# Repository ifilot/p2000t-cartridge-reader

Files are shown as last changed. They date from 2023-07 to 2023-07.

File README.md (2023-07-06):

# P2000T Cartridge Reader

This repository contains hard- and software utilities to read P2000T cartridges
using an [Arduino Leonardo](https://docs.arduino.cc/hardware/leonardo) board.
The repository is organized as follows. The [arduino](arduino) folder contains
the source code for the Arduino Leonardo. In the [kicad](kicad) folder the
files can be found for the arduino shield board. Finally, in the [script](scripts)
folder a number of Python scripts can be found interfacing with the Arduino
Leonardo board to dump cartridge roms to a file.

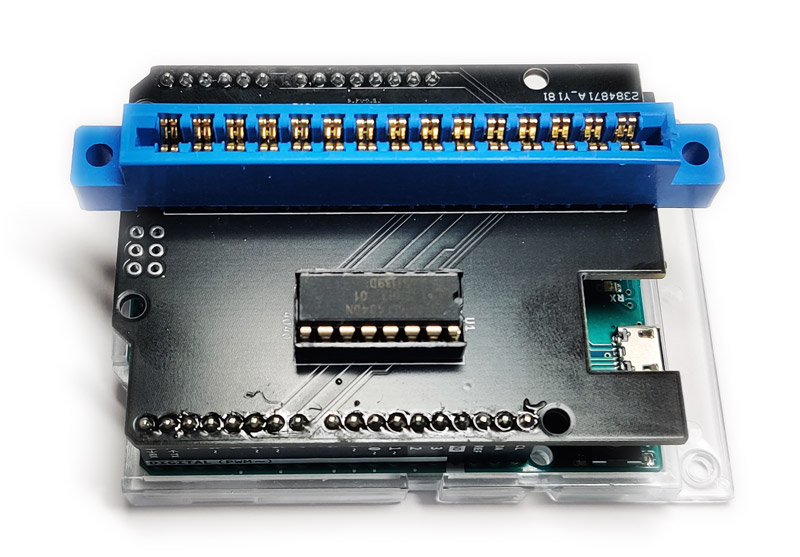
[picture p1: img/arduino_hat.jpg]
Arduino hat


## Kicad scheme

Kicad scheme

## Uploading the firmware

Open the [Arduino IDE](https://www.arduino.cc/en/software) and open the file
`cartridge_reader_firmware.ino`. Verify that the source code can be correctly
compiled and upload it to the Arduino Leonardo. Next, proceed to the Python
files as found below. Test that the interface is functioning and then use
the `readrom.py` file to dump the cartridges.

## Python files

The following three Python files are provided to interface with the Arduino
Leonardo Board. To work with these files, you need to have the
[pyserial](https://pypi.org/project/pyserial/) package installed.

* [serialtest.py](scripts/serialtest.py): Tests whether Python can succesfully
  interface with the Arduino Leonardo and the cartridge reader firmware.
* [comparison_test.py](scripts/comparison_test.py): Tests whether the standard
  basic cartridge can be succesfully read. This requires one to have such a
  cartridge in their possession.
* [readrom.py](scripts/readrom.py): Dumps the contents of the cartridge in
  a `rom.bin` file. The `rom.bin` file is stored in the same folder as where
  this file resides.

## Logic table

In the table below, the interfacing of the Arduino pins to the signals on the
P2000T cartridge can be found. This interfacing scheme has been designed
around the documentation as found [here](https://www.philips-p2000t.nl/cartridges/basic-cartridge).
**It should be explicitly mentioned that the scheme as found in the Field Support
Manual is erroneous and has the CARSEL1 (CS1) and CARSEL2 (CS2) pins swapped.**

| BANK | D8 / A12B | D2 / ~CS1 | D3 / ~CS2 | A12  | A13  | ~CS  |
|---|---|---|---|---|---|---|
|`0x00`| HIGH | LOW | HIGH | LOW  | LOW  | LOW  |
|`0x01`| LOW | LOW | HIGH | HIGH | LOW  | LOW  |
|`0x02`| HIGH | HIGH | LOW | LOW  | HIGH | LOW  |
|`0x03`| LOW | HIGH | LOW | HIGH | HIGH | LOW  |
| N/A  | x | HIGH | HIGH | x | x | HIGH |

## Bill of materials

* Arduino Leonardo
* 2x15 pin edge connector; pitch 3.96mm
* 74HCT4040N or similar

## Picture

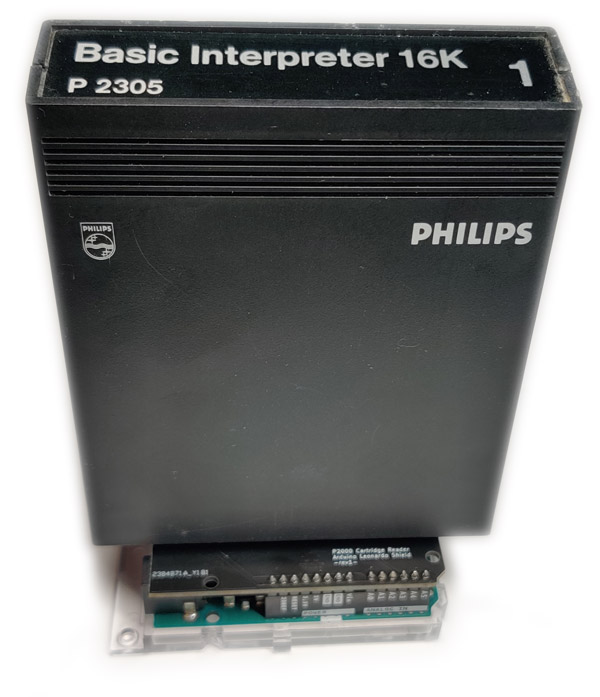
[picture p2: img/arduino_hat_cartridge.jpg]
Arduino hat with cartridge


## Licensing

* All source code, i.e. the [firmware](arduino/cartridge_reader_firmware) and the Python [scripts](scripts)
  are released under a [GPLv3 license](https://www.gnu.org/licenses/gpl-3.0.html).
* The hardware files to (re)produce the Arduino board are released under the 
  [CC BY-SA 4.0](https://creativecommons.org/licenses/by-sa/4.0/) license.

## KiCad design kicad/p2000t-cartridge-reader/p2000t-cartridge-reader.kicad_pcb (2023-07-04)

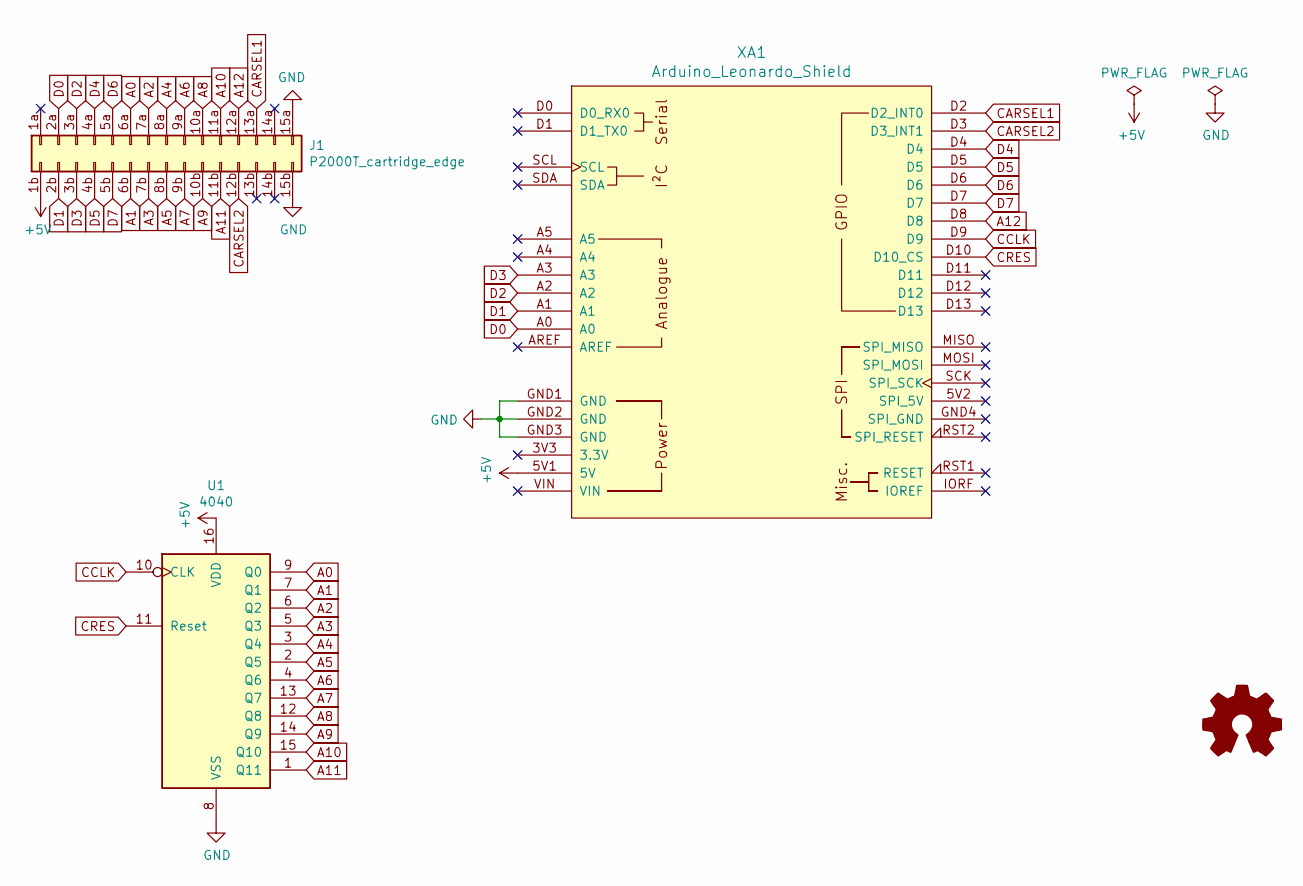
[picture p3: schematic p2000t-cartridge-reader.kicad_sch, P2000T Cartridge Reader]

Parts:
J1: P2000T_cartridge_edge; EdgeConnector2x15_no_screws
U1: 4040; DIP-16_W7.62mm_Socket
XA1: Arduino_Leonardo_Shield; Arduino_Uno_Shield

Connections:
+5V: J1.1b, U1.16 (VDD), XA1.5V1 (5V)
A0: J1.6a, U1.9 (Q0)
A1: J1.6b, U1.7 (Q1)
A2: J1.7a, U1.6 (Q2)
A3: J1.7b, U1.5 (Q3)
A4: J1.8a, U1.3 (Q4)
A5: J1.8b, U1.2 (Q5)
A6: J1.9a, U1.4 (Q6)
A7: J1.9b, U1.13 (Q7)
A8: J1.10a, U1.12 (Q8)
A9: J1.10b, U1.14 (Q9)
A10: J1.11a, U1.15 (Q10)
A11: J1.11b, U1.1 (Q11)
A12: J1.12a, XA1.D8
CARSEL1: J1.13a, XA1.D2 (D2_INT0)
CARSEL2: J1.12b, XA1.D3 (D3_INT1)
CCLK: U1.10 (CLK), XA1.D9
CRES: U1.11 (Reset), XA1.D10 (D10_CS)
D0: J1.2a, XA1.A0
D1: J1.2b, XA1.A1
D2: J1.3a, XA1.A2
D3: J1.3b, XA1.A3
D4: J1.4a, XA1.D4
D5: J1.4b, XA1.D5
D6: J1.5a, XA1.D6
D7: J1.5b, XA1.D7
GND: J1.15a, J1.15b, U1.8 (VSS), XA1.GND1 (GND), XA1.GND2 (GND), XA1.GND3 (GND)

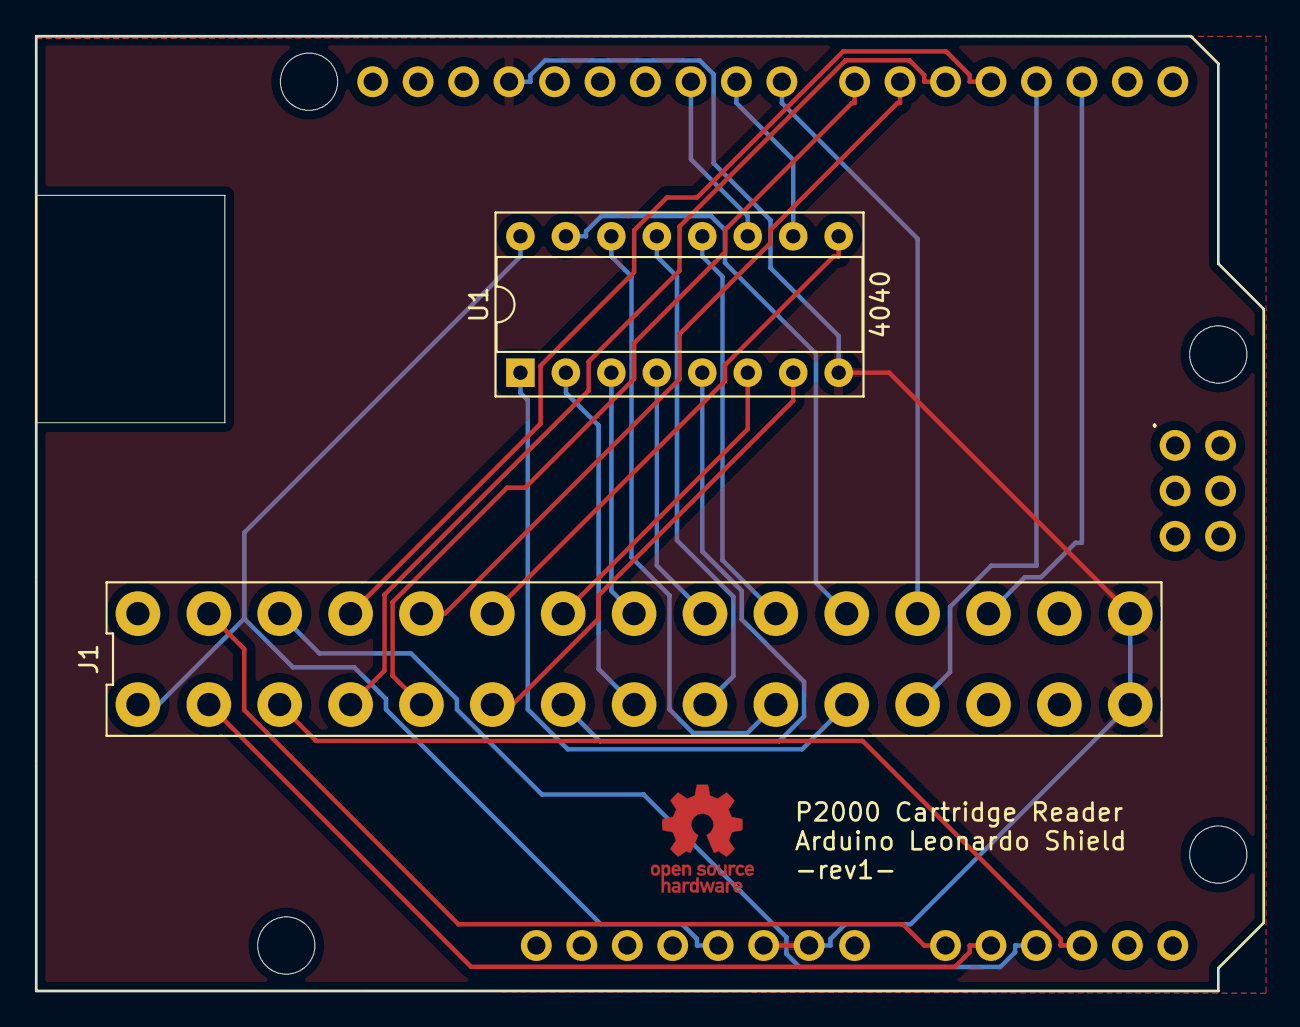
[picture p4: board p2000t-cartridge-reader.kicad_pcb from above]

Board: 2 copper layers, 68.6 x 53.3 mm, 3 parts (0 on the bottom side), 27 nets.

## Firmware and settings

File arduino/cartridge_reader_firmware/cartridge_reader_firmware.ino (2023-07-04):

/*
 * Note that there is an error in the Field Support Manual
 * 
 * CARSEL1 is on PIN 13A and CARSEL2 on PIN 12B; this is presented
 * reversed (incorrectly) in the FSM. See also:
 * https://www.philips-p2000t.nl/cartridges/basic-cartridge
 * 
 * Please note that this script only works for the P2000 Cartridge Reader
 * Boards __REV1__ and higher.
 */

#define ADDR_A12 8
#define ADDR_CARSEL1 2
#define ADDR_CARSEL2 3
#define CCLK 9
#define CRES 10

int lines[8] = {A0,A1,A2,A3,4,5,6,7};

// board identifier; this string needs to be 16 bytes long and terminated by a null character
char board_id[17] = {'P','2','k','0','_','V','1','.','0','.','0','_','_','_','_','_','\0'};

// global variables
char instruction[9];    // stores single 8-byte instruction
uint8_t inptr = 0;      // instruction pointer


void setup() {
  Serial.begin(115200);

  // set output on some pins
  pinMode(ADDR_A12, OUTPUT);
  pinMode(ADDR_CARSEL1, OUTPUT);
  pinMode(ADDR_CARSEL2, OUTPUT);
  pinMode(CCLK, OUTPUT);
  pinMode(CRES, OUTPUT);

  for(int i=0; i<8; i++) {
    pinMode(lines[i], INPUT);
  }

  // disable reset
  digitalWrite(CRES, LOW);
  digitalWrite(CCLK, HIGH);
}

uint8_t read_byte() {
  uint8_t val = 0;
  for(uint8_t i=0; i<8; i++) {
    val |= digitalRead(lines[i]) << i;
  }
  return val;
}

void set_address_start(uint16_t addr) {
  // reset counter
  digitalWrite(CRES, HIGH);
  digitalWrite(CRES, LOW);

  // read cartridge address
  bool a12 = bitRead(addr, 12);
  bool a13 = bitRead(addr, 13);
  uint8_t idx = a12 | (a13 << 1);

  // calculate load on cartridge lines
  static const bool a12p[4] = {HIGH,LOW,HIGH,LOW};
  static const bool cs1[4] = {LOW,LOW,HIGH,HIGH};
  static const bool cs2[4] = {HIGH,HIGH,LOW,LOW};

  // write to cartridge
  digitalWrite(ADDR_A12, a12p[idx]);
  digitalWrite(ADDR_CARSEL1, cs1[idx]);
  digitalWrite(ADDR_CARSEL2, cs2[idx]);
}

/*
 * Read block of 4096 bytes and output this
 * to the serial interface
 */
static void read_sector(uint16_t startaddress) {
  set_address_start(startaddress);
  for(int i=0; i<4096; i++) {
    Serial.write(read_byte());
    digitalWrite(CCLK, LOW);
    digitalWrite(CCLK, HIGH);
  }
}

/*
 * Capture address from last 6 bytes
 * of a command word
 */
static uint16_t get_addr_cmdword(const char* command) {
  char adrstr[7] = {'\0','\0','\0','\0','\0','\0','\0',};
  for(int i=0; i<6; i++) {
    adrstr[i] = command[i+2];
  }
  uint16_t saddr = strtoul(adrstr, NULL, 16);
  return saddr;
}

void loop() {
  if (Serial.available() > 0) {
    char c = Serial.read();

    // only capture alphanumerical data
    if((c >= 48 && c <= 57) || (c >= 65 && 90)) {
      instruction[inptr] = c;
      inptr++;
    }
  }

  // parse instruction
  if(inptr == 8) {
    // reset pointer
    inptr = 0;

    // interpret commands
    if(strcmp(instruction, "READINFO") == 0) {                    // read board id
      Serial.print(instruction);
      Serial.print(board_id);
    } else if(instruction[0] == 'R' && instruction[1] == 'B') {   // read sector
      Serial.print(instruction);
      uint16_t saddr = get_addr_cmdword(instruction);
      read_sector(saddr);
    }
  }
}

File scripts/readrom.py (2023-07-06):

# -*- coding: utf-8 -*-

#
# Read a cartridge via the P2000T Cartridge Reader Board and store it
# as a 'rom.bin' file.
#

import serial
import re

def main():
    # auto-find port
    port = find_port()
    assert(port)

    # specify the COM port below
    ser = serial.Serial(port, 
                        115200, 
                        bytesize=serial.EIGHTBITS,
                        parity=serial.PARITY_NONE,
                        stopbits=serial.STOPBITS_ONE,
                        timeout=1.5)  # open serial port
    
    if not ser.isOpen():
        ser.open()
    
    # check that the correct board is attached
    ser.write(b'READINFO')
    rsp = ser.read(8)
    rsp = ser.read(16)
    print(rsp)
    
    # read 16 kb from cartridge
    data = bytearray()
    for i in range(0,4):
        ser.write(b'RB%06X' % (i*4096))
        print('Reading bank %i' % i)
        rsp = ser.read(8)
        rsp = ser.read(0x1000)
        data.extend(rsp)
    ser.close()
    
    print()
    print('First 256 bytes read:')
    for j in range(0,16):
        for i in range(0, 16):
            print('%02X ' % data[j*16+i], end='')
        print()
    
    # store in file
    f = open('rom.bin', 'wb')
    f.write(data)
    f.close()
    
def find_port():
    """
    Find the correct port by looping over all ports and looking for one
    that has an hardware id matching an Arduino Leonardo
    """
    ports = serial.tools.list_ports.comports()
    pattern = r'USB VID:PID=([0-9:]+) SER=.*'
    for port,desc,hwid in ports:
        match = re.match(pattern, hwid)
        if match is not None:
            if match.group(1) == '2341:8036':
                return port
    
    return False

if __name__ == '__main__':
    main()

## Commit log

2023-07-04 Adding Kicad files
    [p2000t-cartridge-reader-B_Cu.gbr, p2000t-cartridge-reader-B_Mask.gbr, p2000t-cartridge-reader-B_Paste.gbr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]
2023-07-06 Fixing code in readrom function
    [readrom.py]
